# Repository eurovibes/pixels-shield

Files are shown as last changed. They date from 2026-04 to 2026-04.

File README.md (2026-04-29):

<!-- SPDX-FileCopyrightText: 2026 Benedikt Spranger <b.spranger@linutronix.de> -->
<!-- SPDX-License-Identifier: CERN-OHL-S-2.0 -->




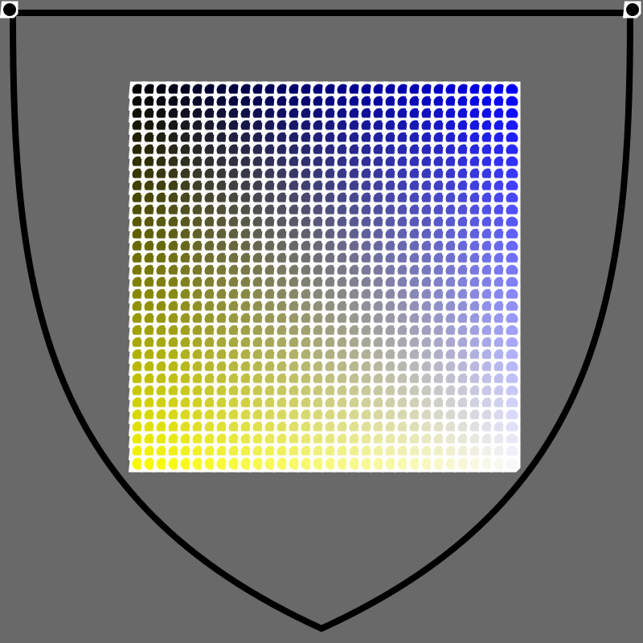
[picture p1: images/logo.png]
pixels-shield logo


# pixels-shield - We need a shield for pixels!

A Arduino UNO R3 shield to control [pixels](https://github.com/eurovibes/pixels).

## License rules

pixels-shield is provided under the terms of the CERN-OHL-S license version 2
as provided in the LICENSES/CERN-OHL-S-2.0 file.

Instead of adding license boilerplates to the individual files, pixels-shield
uses SPDX license identifiers, which are machine parseable and considered
legaly equivalent.

The SPDX license identifier in pixels-shield shall be added at the first
possible line in a file which can contain a comment. This is normally the
first line except for scripts. Scripts require the #!PATH_TO_INTERPRETER tag
in the first line; place the SPDX identifier into the second line.

The SPDX license identifier is added in form of a comment.

## Copyright and License

Copyright Benedikt Spranger 2026.
This source describes Open Hardware and is licensed under the CERNOHL-S v2.
You may redistribute and modify this source and make products using it
under the terms of the CERN-OHL-S v2
(https://ohwr.org/cern ohl s v2.txt ).
This source is distributed WITHOUT ANY EXPRESS OR IMPLIED
WARRANTY, INCLUDING OF MERCHANTABILITY, SATISFACTORY
QUALITY AND FITNESS FOR A PARTICULAR PURPOSE. Please see
the CERN-OHL-S v2 for applicable conditions.
Source location: https://github.com/eurovibes/pixels-shield
As per CERN-OHL-S v2 section 4, should You produce hardware based
on this source, You must where practicable maintain the Source Location
visible on the external case of the pixels-shield or other products you make
using this source.

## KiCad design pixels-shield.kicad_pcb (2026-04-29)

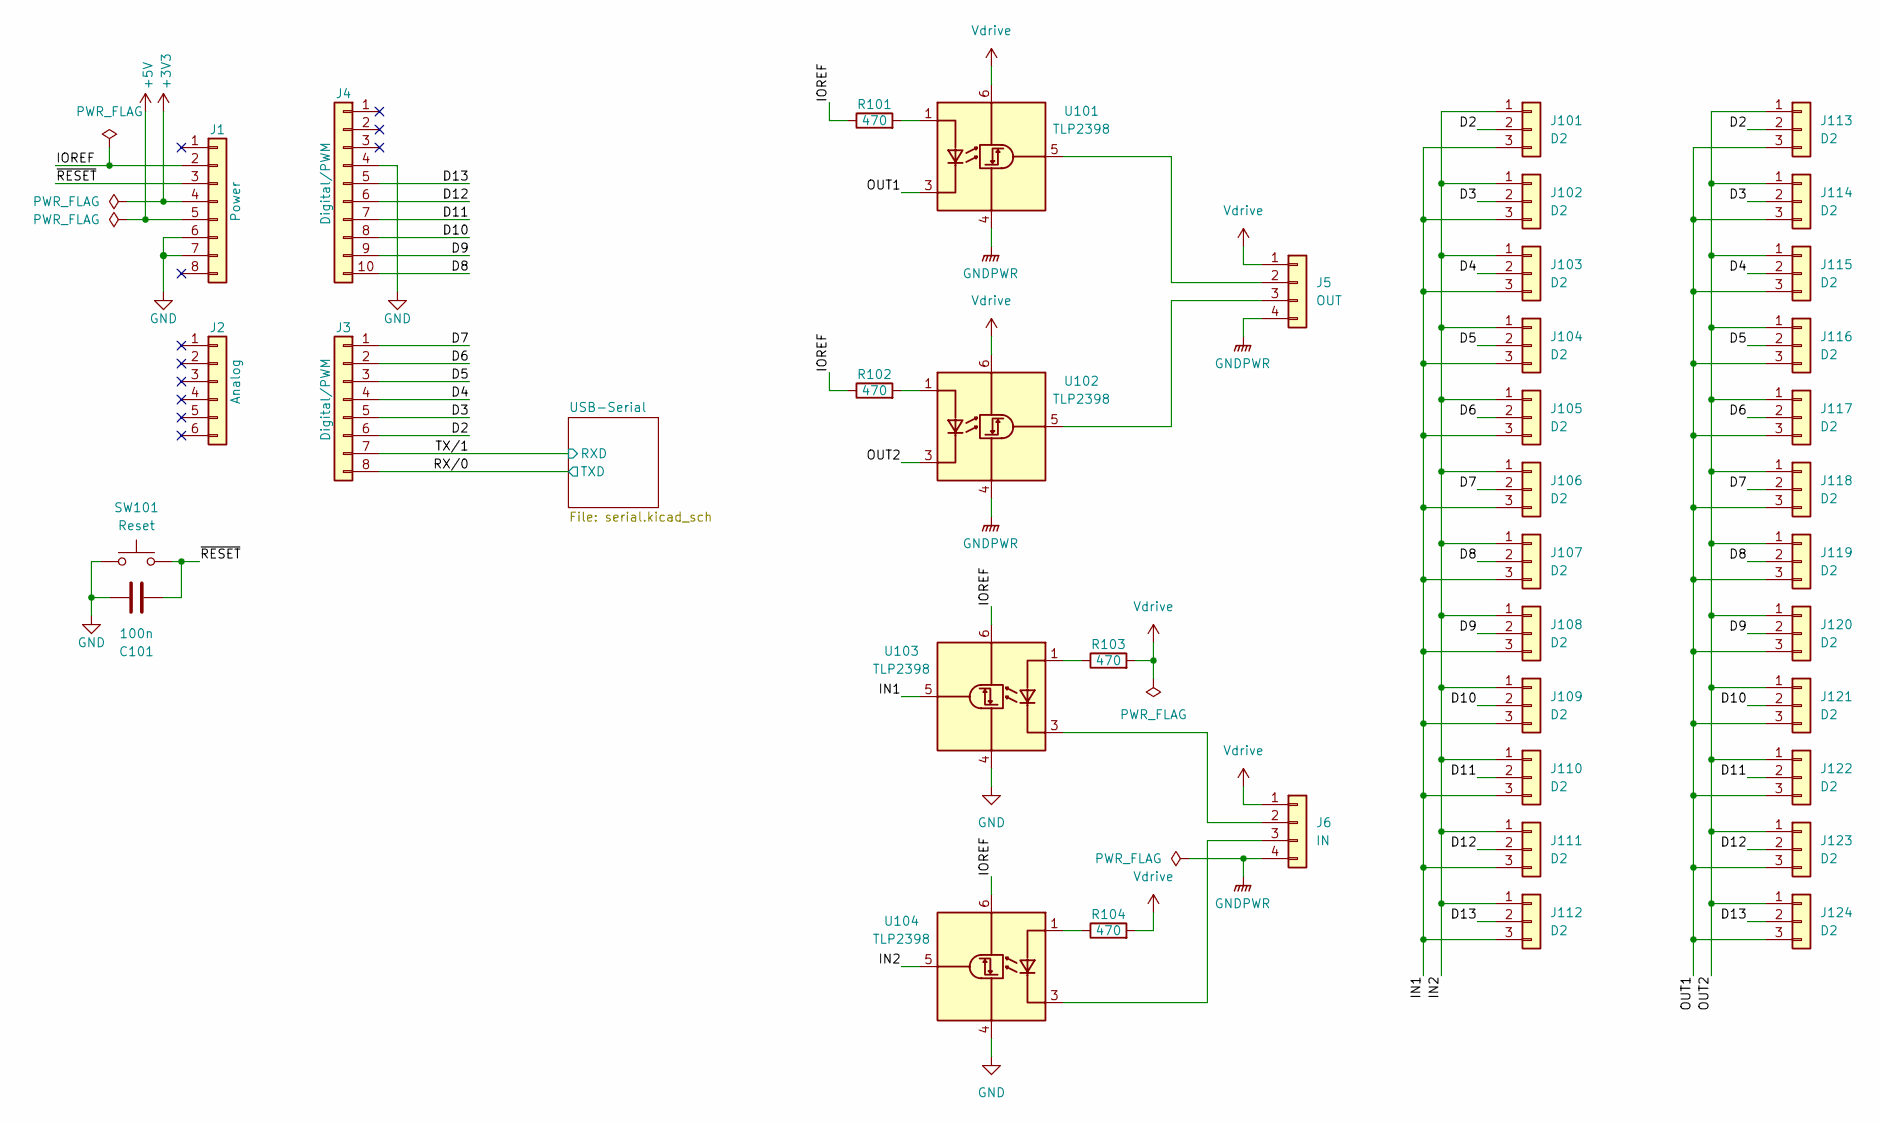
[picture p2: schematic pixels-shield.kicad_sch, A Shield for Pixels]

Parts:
C101: 100n; C_0402_1005Metric; mpn CL05B104KB54PNC; LCSC# C307331
J1: Power; PinSocket_1x08_P2.54mm_Vertical
J2: Analog; PinSocket_1x06_P2.54mm_Vertical
J3: Digital/PWM; PinSocket_1x08_P2.54mm_Vertical
J4: Digital/PWM; PinSocket_1x10_P2.54mm_Vertical
J5: OUT; TerminalBlock_WAGO_236-404_1x04_P5.00mm_45Degree
J6: IN; TerminalBlock_WAGO_236-404_1x04_P5.00mm_45Degree
J101, J102, J103, J104, J105, J106, J107, J108, J109, J110, J111, J112, J113, J114, J115, J116, J117, J118, J119, J120, J121, J122, J123, J124: D2; PinHeader_1x03_P1.27mm_Vertical
R101, R102, R103, R104: 470; R_0402_1005Metric; mpn 0402WGF4700TCE; LCSC# C25117
SW101: Reset; SW_Push_1P1T_XKB_TS-1187A; mpn TS-1187A-B-A-B; LCSC# C318884
U101, U102, U103, U104: TLP2398; SO-5-6_4.55x3.7mm_P1.27mm; mpn TLP2398; LCSC# C5370545

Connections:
+3V3: J1.4
+5V: J1.5
/D2: J3.6, J101.2, J113.2
/D3: J3.5, J102.2, J114.2
/D4: J3.4, J103.2, J115.2
/D5: J3.3, J104.2, J116.2
/D6: J3.2, J105.2, J117.2
/D7: J3.1, J106.2, J118.2
/D8: J4.10, J107.2, J119.2
/D9: J4.9, J108.2, J120.2
/D10: J4.8, J109.2, J121.2
/D11: J4.7, J110.2, J122.2
/D12: J4.6, J111.2, J123.2
/D13: J4.5, J112.2, J124.2
/IN1: J101.3, J102.3, J103.3, J104.3, J105.3, J106.3, J107.3, J108.3, J109.3, J110.3, J111.3, J112.3, U103.5 (VO)
/IN2: J101.1, J102.1, J103.1, J104.1, J105.1, J106.1, J107.1, J108.1, J109.1, J110.1, J111.1, J112.1, U104.5 (VO)
/IOREF: J1.2, R101.1, R102.1, U103.6 (VDD), U104.6 (VDD)
/OUT1: J113.3, J114.3, J115.3, J116.3, J117.3, J118.3, J119.3, J120.3, J121.3, J122.3, J123.3, J124.3, U101.3 (K)
/OUT2: J113.1, J114.1, J115.1, J116.1, J117.1, J118.1, J119.1, J120.1, J121.1, J122.1, J123.1, J124.1, U102.3 (K)
/RX/0: J3.8; also elsewhere on the board
/TX/1: J3.7; also elsewhere on the board
/~RESET: C101.1, J1.3, SW101.1
GND: C101.2, J1.6, J1.7, J4.4, SW101.2, U103.4 (GND), U104.4 (GND); also elsewhere on the board
GNDPWR: J5.4, J6.4, U101.4 (GND), U102.4 (GND)
unnamed: J5.2, U101.5 (VO)
unnamed: J5.3, U102.5 (VO)
unnamed: J6.2, U103.3 (K)
unnamed: J6.3, U104.3 (K)
unnamed: R101.2, U101.1 (A)
unnamed: R102.2, U102.1 (A)
unnamed: R103.1, U103.1 (A)
unnamed: R104.1, U104.1 (A)
Vdrive: J5.1, J6.1, R103.2, R104.2, U101.6 (VDD), U102.6 (VDD)

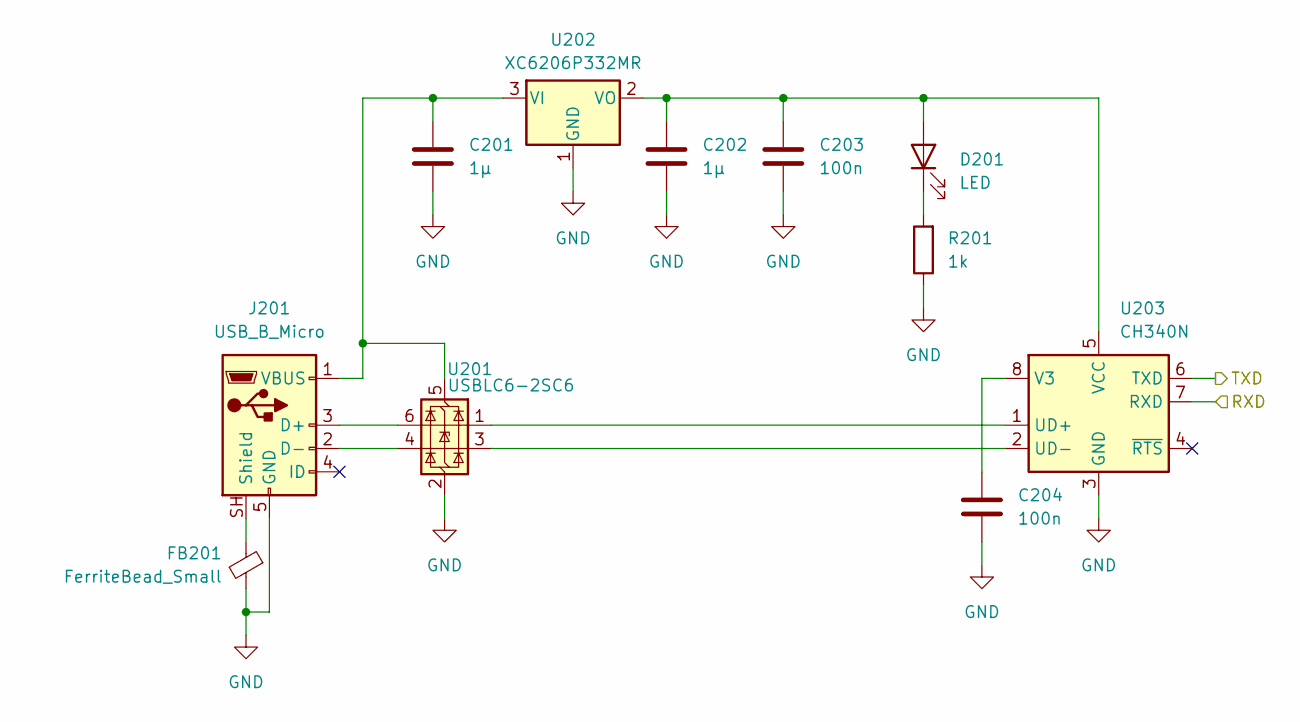
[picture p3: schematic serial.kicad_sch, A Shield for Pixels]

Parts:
C201, C202: 1µ; C_0603_1608Metric; mpn CL10A105KB8NNNC; LCSC# C15849
C203, C204: 100n; C_0402_1005Metric; mpn CL05B104KB54PNC; LCSC# C307331
D201: LED; LED_0603_1608Metric; mpn KT-0603R; LCSC# C2286
FB201: FerriteBead_Small; L_0603_1608Metric; mpn GZ1608D601TF; LCSC# C1002
J201: USB_B_Micro; USB_Micro-B_Amphenol_10118193-0001LF_Horizontal; mpn 10118193-0001LF; LCSC# C132562
R201: 1k; R_0402_1005Metric; mpn 0402WGF1001TCE; LCSC# C11702
U201: USBLC6-2SC6; SOT-23-6; mpn USBLC6-2SC6; LCSC# C2827654
U202: XC6206P332MR; SOT-23-3; mpn XC6206P332MR-G; LCSC# C5446
U203: CH340N; JEITA_SOIC-8_3.9x4.9mm_P1.27mm; mpn CH340N; LCSC# C2977777

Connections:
/RX/0: U203.6 (TXD); also elsewhere on the board
/TX/1: U203.7 (RXD); also elsewhere on the board
GND: C201.2, C202.2, C203.2, C204.2, FB201.2, J201.5 (GND), R201.1, U201.2 (GND), U202.1 (GND), U203.3 (GND); also elsewhere on the board
unnamed: C202.1, C203.1, D201.2 (A), U202.2 (VO), U203.5 (VCC)
unnamed: D201.1 (K), R201.2
unnamed: J201.3 (D+), U201.6 (I/O1)
unnamed: J201.2 (D-), U201.4 (I/O2)
unnamed: FB201.1, J201.SH (Shield)
unnamed: C201.1, J201.1 (VBUS), U201.5 (VBUS), U202.3 (VI)
unnamed: U201.1 (I/O1), U203.1 (UD+)
unnamed: U201.3 (I/O2), U203.2 (UD-)
unnamed: C204.1, U203.8 (V3)

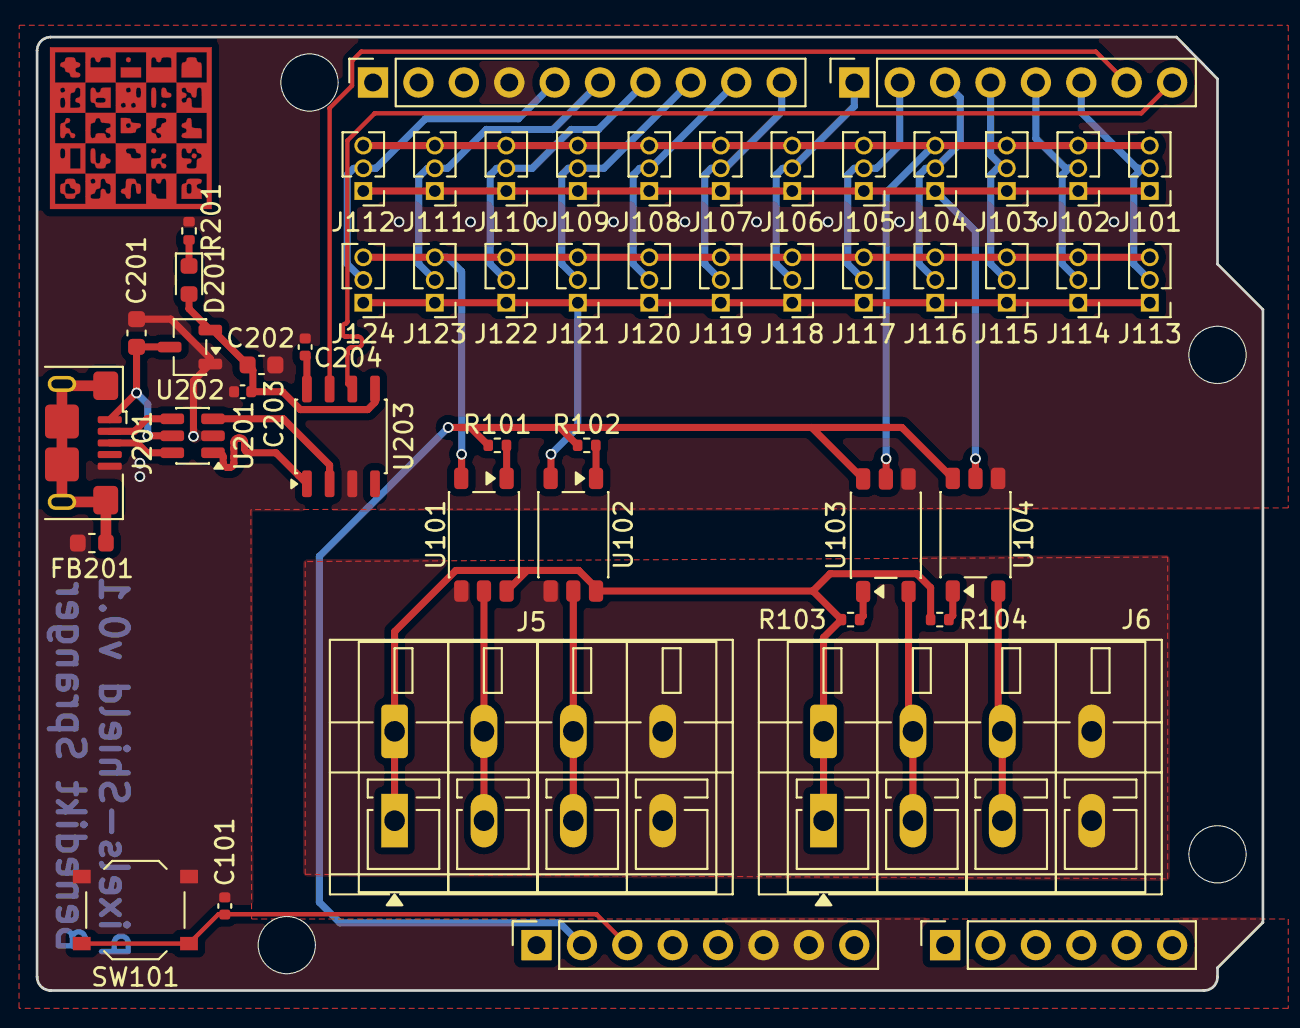
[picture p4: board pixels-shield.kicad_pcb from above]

Board: 2 copper layers, 68.6 x 53.3 mm, 55 parts (0 on the bottom side), 40 nets.

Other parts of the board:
MH1, MH2, MH3, MH4: MountingHole_3.2mm

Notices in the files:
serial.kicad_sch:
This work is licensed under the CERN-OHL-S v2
